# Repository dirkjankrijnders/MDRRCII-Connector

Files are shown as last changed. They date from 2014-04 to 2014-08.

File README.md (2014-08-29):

MDRRCII-Connector
=================

This is a small interface board to connect the [Mini STM32 board](http://www.ebay.com/itm/MINI-V3-STM32F103RBT6-development-board-with-2-8-TFT-module-/121287420704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) as used in [MDRRC II](http://members.home.nl/robert.evers/mdrrc2.htm) its peripherals. It is effectively all of the schematics in the manual on a nice board. It uses a DIN5 connector for I2C controller and also has a [S88N](http://www.s88-n.eu) pin-compatible RJ45 connection. Its power it receives from a 4-pin molex connector as commonly found in computers. By default this also powers the STM32, which is not desirable unless an USB isolator is used. 

It also includes a USB isolator, not necessary for normal operation, but when fiddling around I'd rather blow the 10 euro isolator than my laptops usb port. It also 

Unchecked Reichelt shopping card:
http://www.reichelt.de/?ACTION=20;AWKID=901501;PROVID=2084

STATUS
------
Board for Rev.0 are on order and recieved. The first board is build and very lightly tested with MDRRC version one, due to a rather lengthy remodeling of my train room (well actually, the creation of...). Below is a photo of the prototype. Testing with MDRRC-II is under way though.

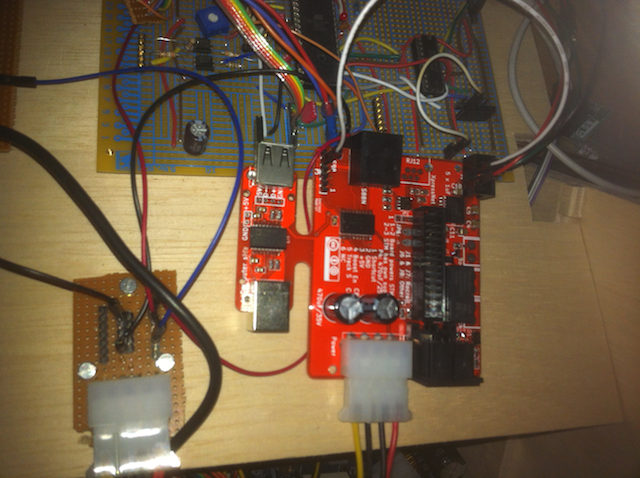
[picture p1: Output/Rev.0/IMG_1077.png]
Photo of the first prototype


<table>
<tr>
<th>Function</th><th>test</th>
</tr>
<tr><td>Power</td><td>Passed</td></tr>
<tr><td>Booster connection</td><td>Passed</td></tr>
<tr><td>S88N</td><td>Passed*</td></tr>
<tr><td>I2C</td><td>Failed, see issue #1</td></tr>
<tr><td>Programming</td><td>Untested</td></tr>
<tr><td>Expressnet</td><td>Untested</td></tr>
</table>
* Works, but S88N signal specifications remain untested until now.

LICENSE
-------

Both hardware and firmware are placed under the Creative Commons Attribution-ShareAlike 3.0 Unported License. See <http://creativecommons.org/licenses/by-sa/3.0/> and License.txt for more details.

Copyright 2014
Dirkjan Krijnders
<dirkjan@krijnders.net>

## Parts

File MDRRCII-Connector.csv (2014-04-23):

ref | value | Field1 | Field2 | Field3 | Field4 | Field5 | Field6 | Field7 | Field8
C1 | 100nF
C2 | 100nF
C3 | 100nF
C4 | 1uF
C5 | 1uF
C6 | 470uF/35V
C7 | 100nF
C8 | 470uF/25V
C9 | 100nF
C10 | 1uF
C11 | 1uF
C12 | 100nF
C13 | 1uF
C14 | 33nF
D1 | S1G
D2 | S1G
J1 | SOLDER_JUMPER_CONN
J2 | USB
J3 | RJ12
J4 | USB_2 | VCC | D+ | D- | GND
J5 | RJ45
J6 | SOLDER_JUMPER
J7 | SOLDER_JUMPER_CONN
J8 | SOLDER_JUMPER
JP1 | JUMPER
K1 | RELAY_M4
P1 | DIN_5
P2 | CONN_4
P3 | CONN_STM32_P1
P4 | CONN_3X2
P5 | CONN_6
P6 | CONN_2
P7 | CONN_4
P8 | CONN_2
P9 | CONN_2
P10 | CONN_2
Q1 | BC847
R1 | 1K
R2 | 1K
R3 | 1K
R4 | 100
R5 | 100
R6 | 24 1%
R7 | 4K7
R8 | 24 1%
R9 | 4K7
R10 | 120
R11 | 1K5
R12 | 1K5
R13 | 24 1%
R14 | 24 1%
R15 | 39
R16 | 680
R17 | 1K
R18 | 47k
U1 | MAX485
U2 | ADuM4160 | 2061081 | ADUM 4160
U3 | MAX232 | 9725962 | MAX 232 CWE
U4 | 74LS244
U5 | PC814

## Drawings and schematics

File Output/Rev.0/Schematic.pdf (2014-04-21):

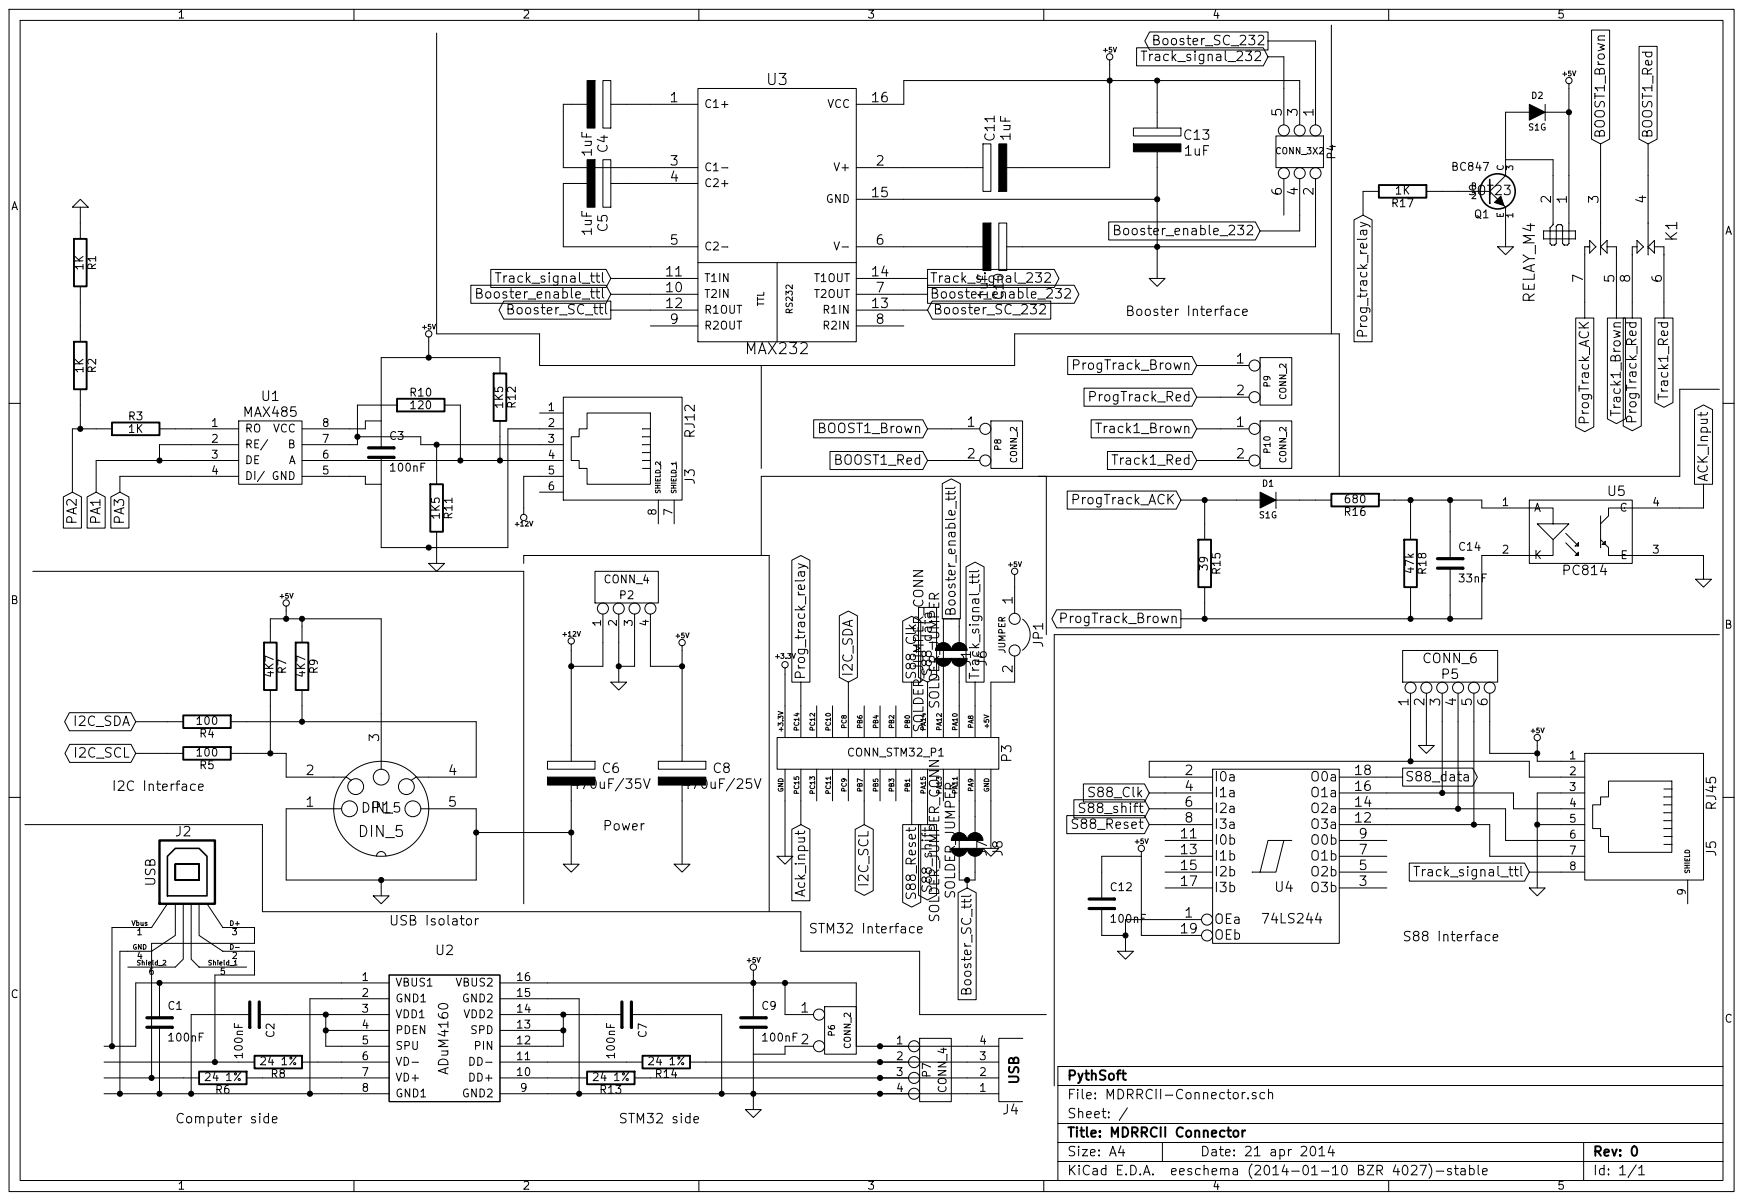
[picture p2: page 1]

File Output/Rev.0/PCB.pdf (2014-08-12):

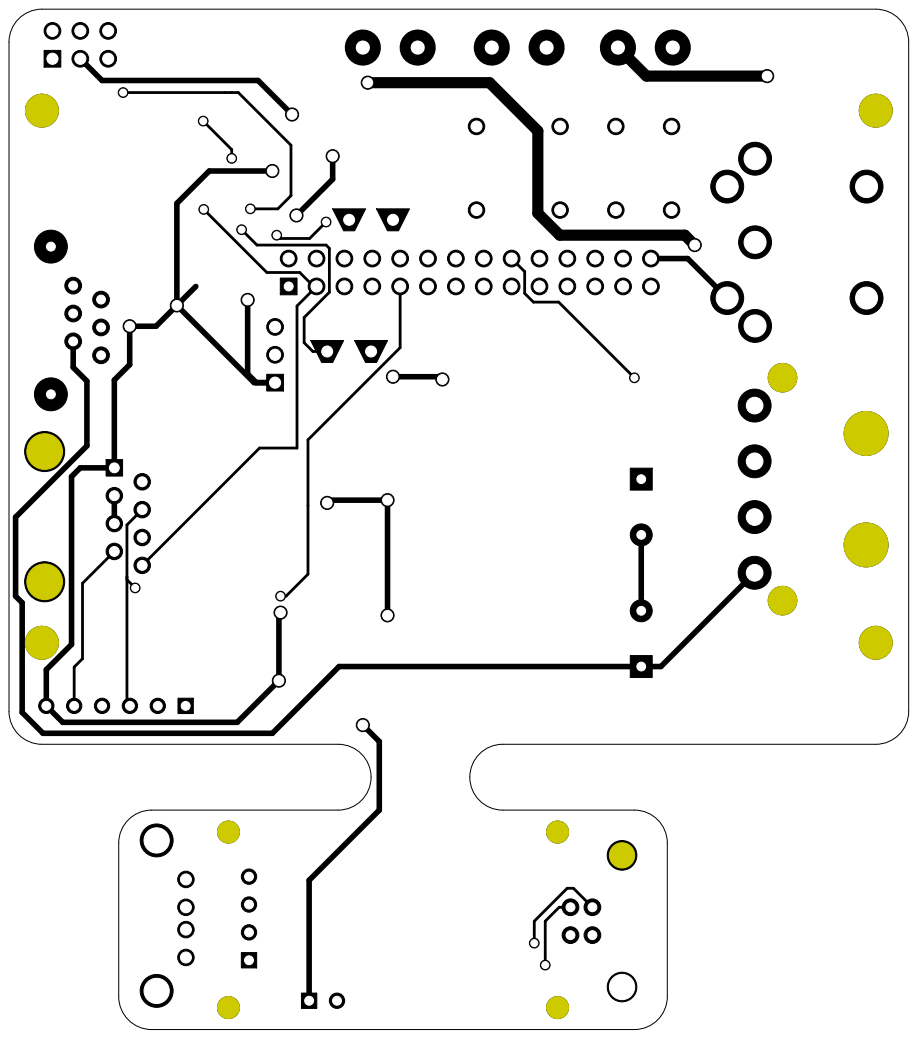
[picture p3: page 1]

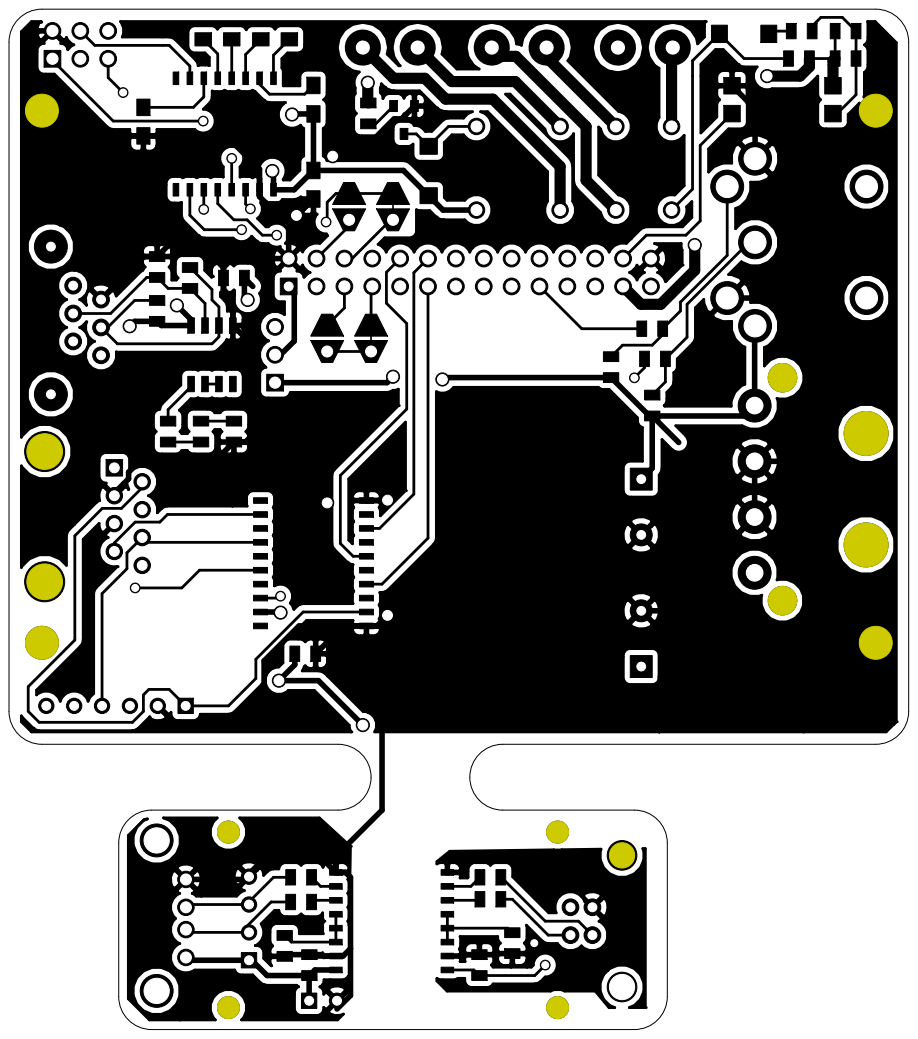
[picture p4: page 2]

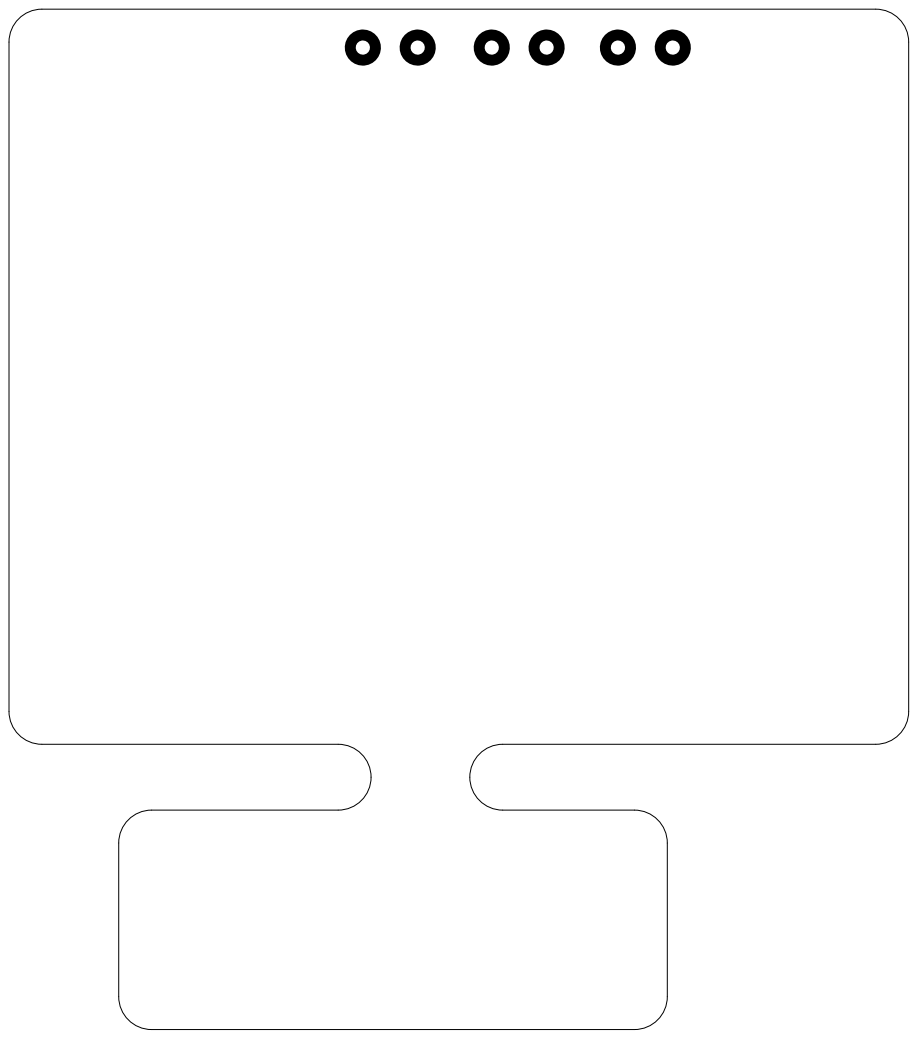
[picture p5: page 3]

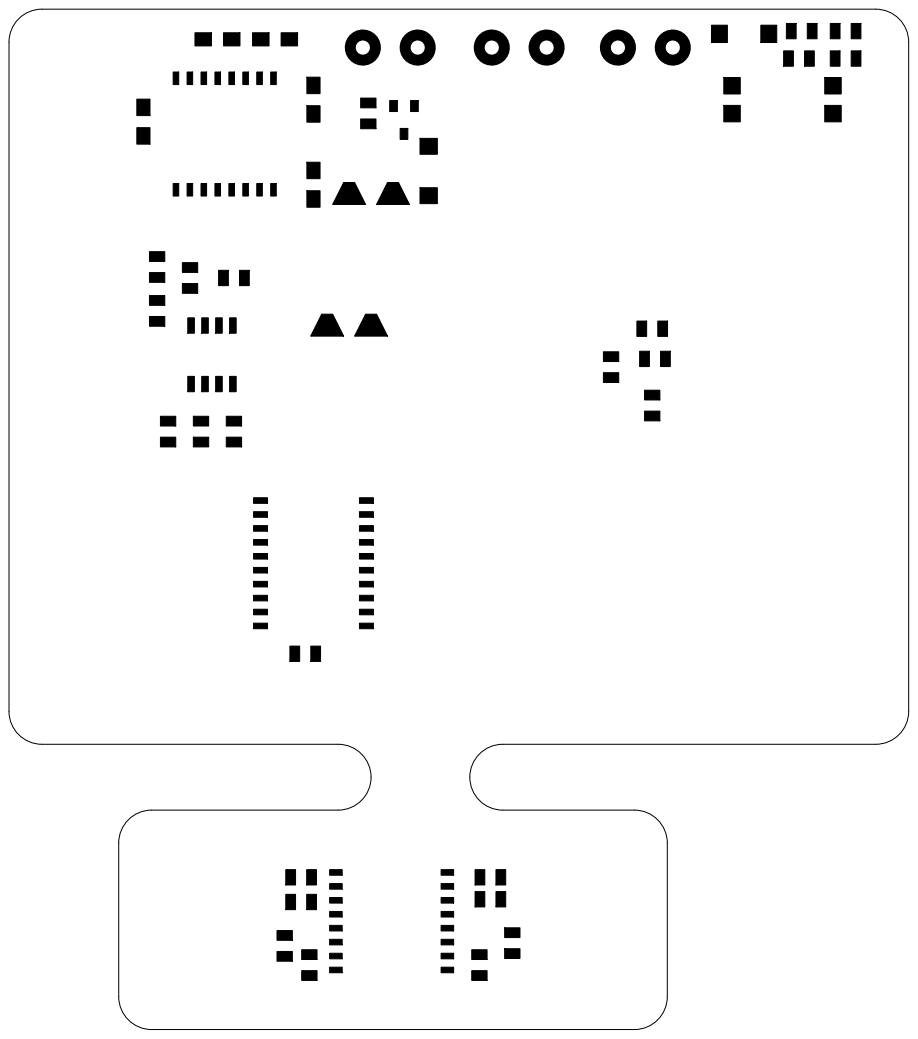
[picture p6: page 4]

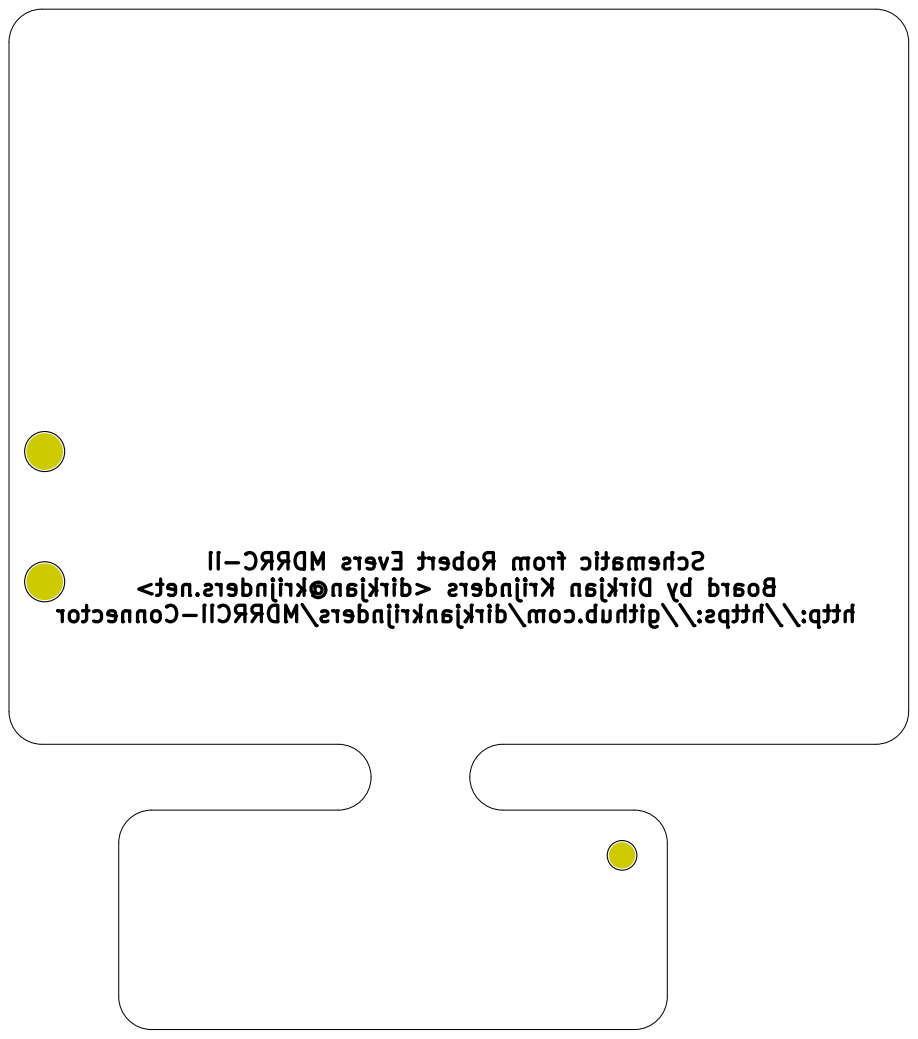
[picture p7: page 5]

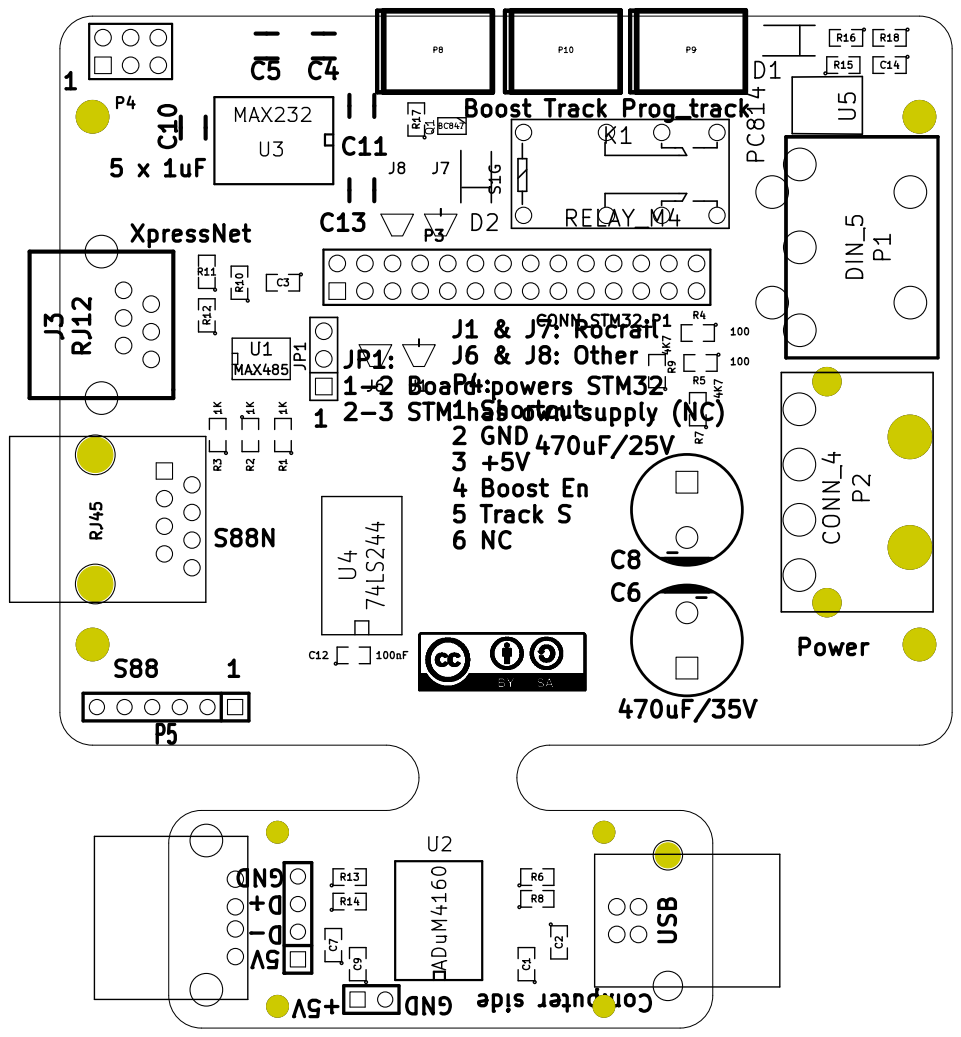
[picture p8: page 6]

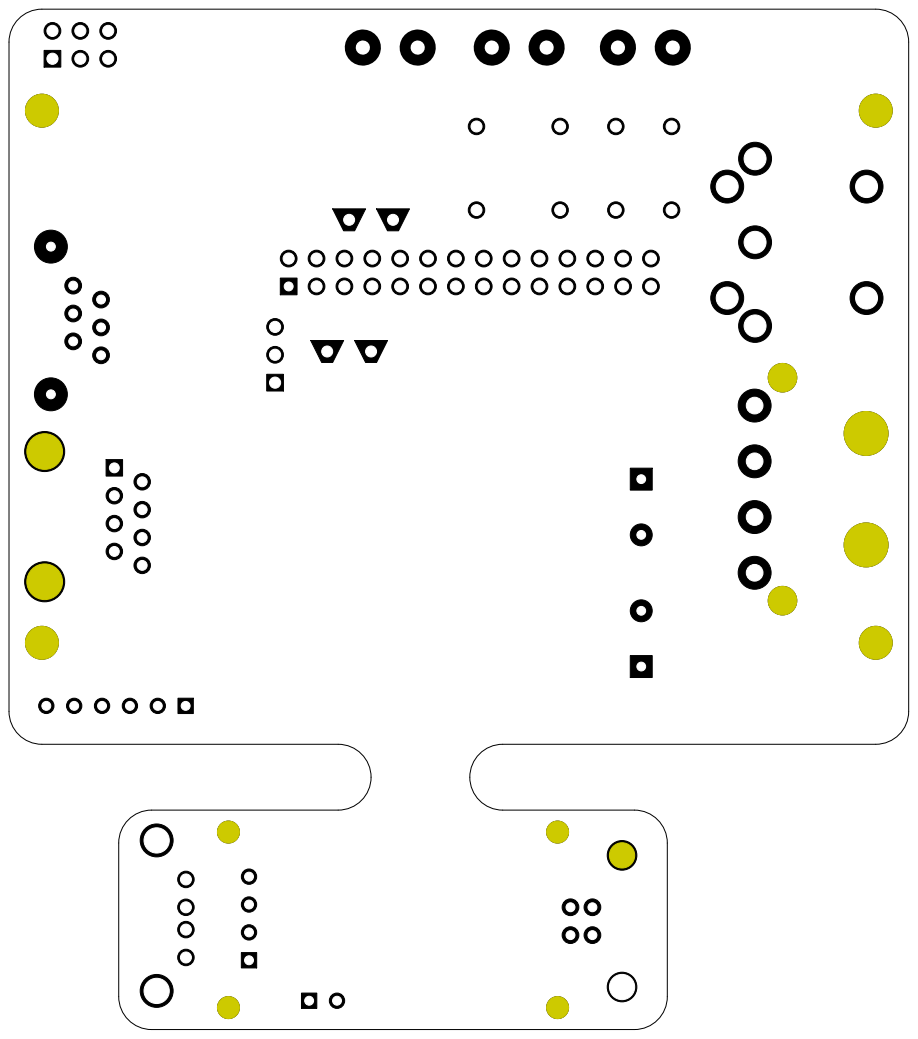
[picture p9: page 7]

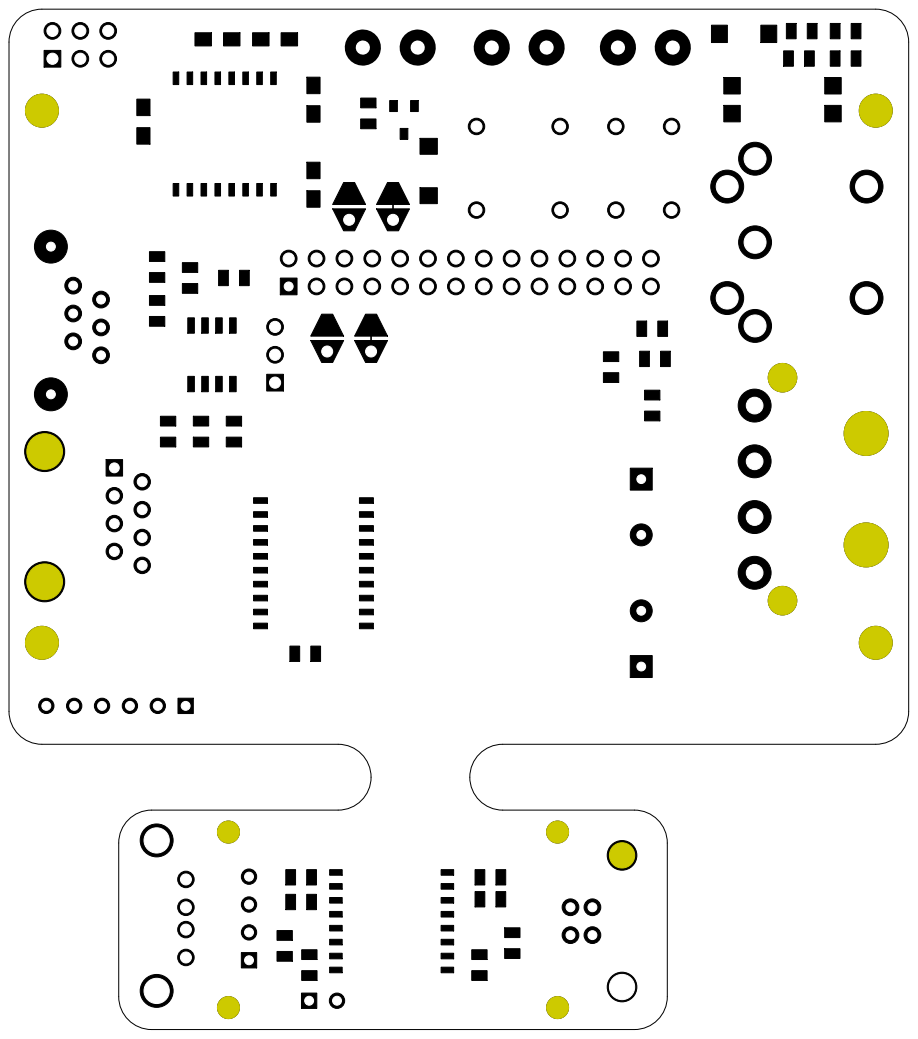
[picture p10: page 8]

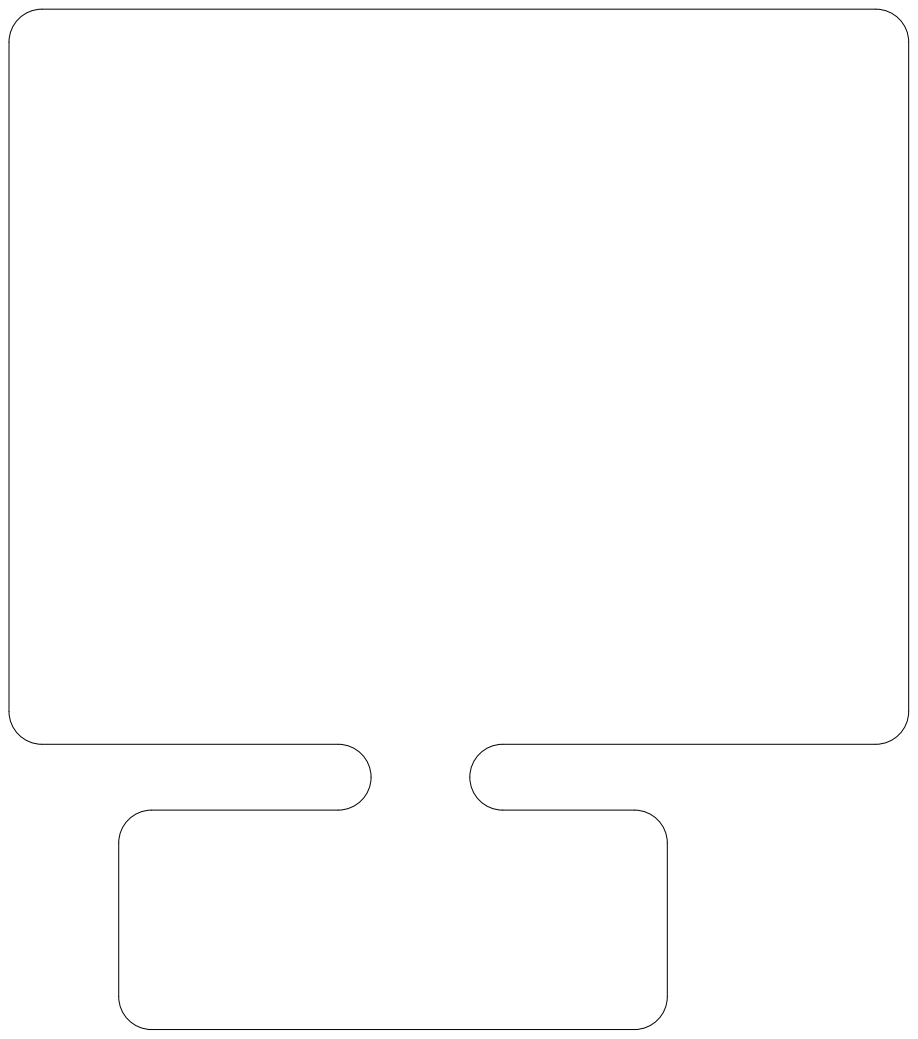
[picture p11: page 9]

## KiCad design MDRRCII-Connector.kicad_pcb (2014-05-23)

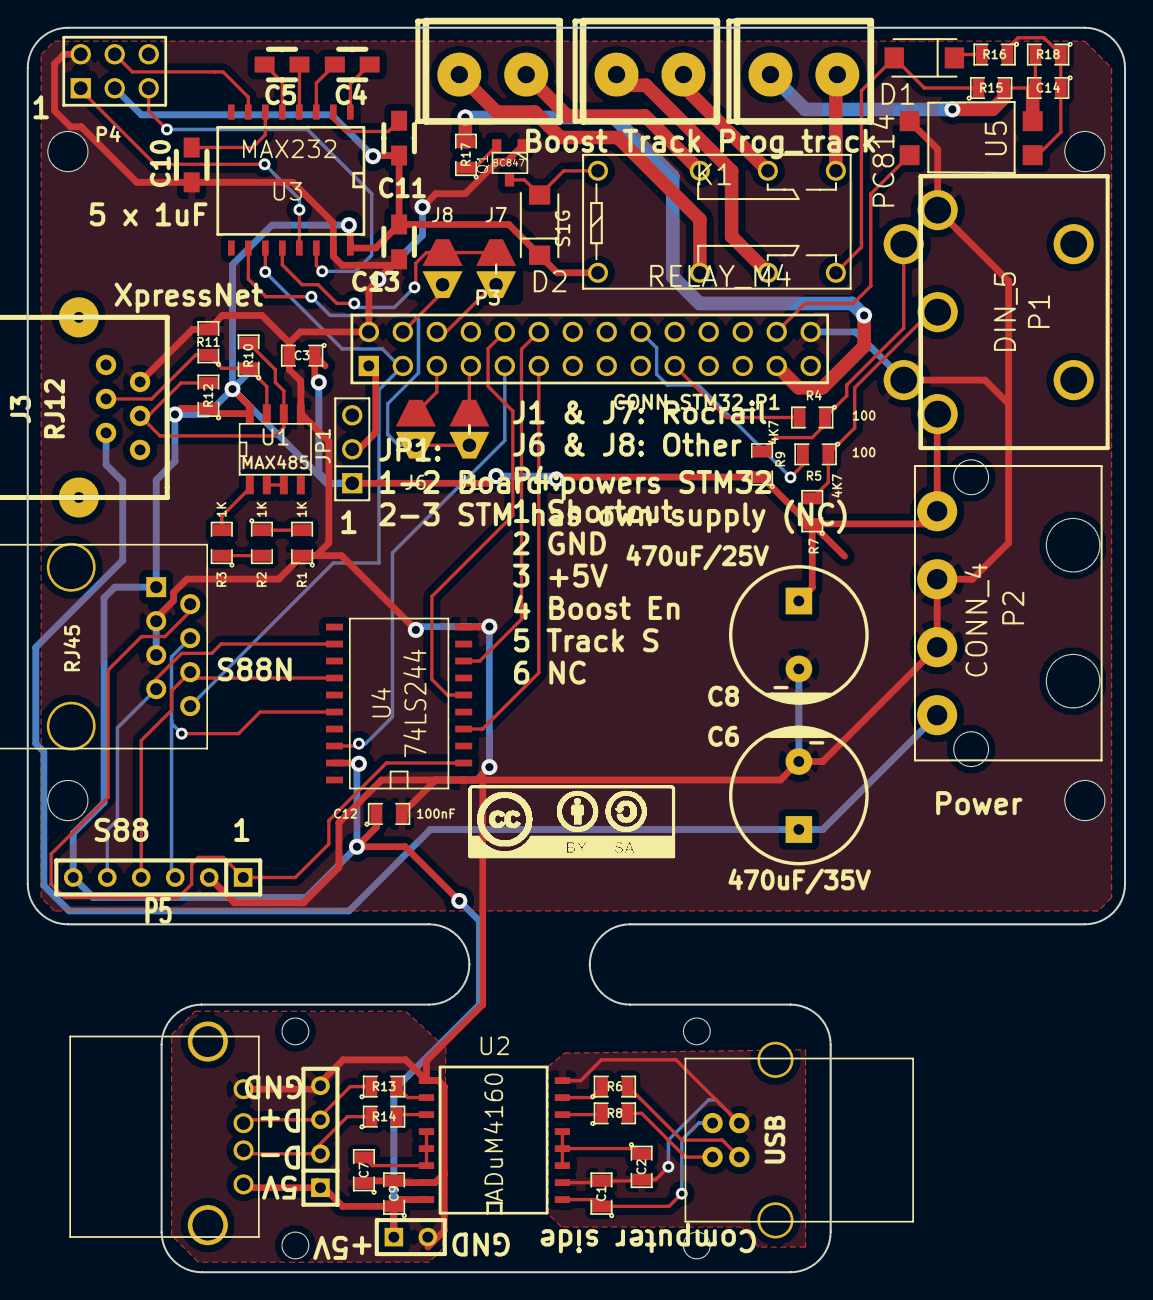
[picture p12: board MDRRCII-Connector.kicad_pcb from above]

Board: 2 copper layers, 82.0 x 93.0 mm, 68 parts (0 on the bottom side), 63 nets.

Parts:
C1, C2, C3, C7, C9, C12: 100nF; SM0805
C4, C5, C10, C11, C13: 1uF; Capacitor_SMD0805_HandSoldering_RevA_Date21Jun2010
C6: 470uF/35V; CP_10x21mm
C8: 470uF/25V; CP_10x21mm
C14: 33nF; SM0805
D1, D2: S1G; DO-214AC
J1, J7: SOLDER_JUMPER_CONN; solder_jumper_conn
J2: USB; USB_B
J3: RJ12; RJ12_E
J4: USB_2; USB_A
J5: RJ45; RJ45_8
J6, J8: SOLDER_JUMPER; solder_jumper
JP1: JUMPER; PIN_ARRAY_3X1
K1: RELAY_M4; Relais_M4
M2, M2#2, M2#3, M2#4, M2#5, M2#6, M2#7, M2#8: VAL**; M2
P1: DIN_5
P2: CONN_4; MOLEX_15-24-4441
P3: CONN_STM32_P1; pin_array_14x2
P4: CONN_3X2; pin_array_3x2
P5: CONN_6; SIL-6
P6: CONN_2; SIL-2
P7: CONN_4; SIL-4
P8, P9, P10: CONN_2; 2PIN_SC_RM5
Q1: BC847; SOT23
R1, R2, R3, R17: 1K; SM0805
R4, R5: 100; SM0805
R6, R8, R13, R14: 24 1%; SM0805
R7, R9: 4K7; SM0805
R10: 120; SM0805
R11, R12: 1K5; SM0805
R15: 39; SM0805
R16: 680; SM0805
R18: 47k; SM0805
U1: MAX485; SO8E
U2: ADuM4160; SO16W
U3: MAX232; SO16W
U4: 74LS244; SO20L
U5: PC814; 4LD_MDIP

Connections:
+5V: C3.1, C8.1, C9.1, C11.2, C12.1, C13.1, D2.2, J4.4, J5.1, JP1.1, K1.1, P1.3, P2.4, P4.3, P5.6, P6.1, P7.1, R7.1, R9.1, R12.1, U1.8, U2.16, U3.16, U4.19
+12V: C6.1, J3.5, P2.1
ACK_Input: P3.26, U5.4
BOOST1_Brown: K1.3, P8.1
BOOST1_Red: K1.4, P8.2
Booster_SC_232: P4.1, U3.13
Booster_SC_ttl: J7.1, J8.1, U3.12
Booster_enable_232: P4.4, U3.7
Booster_enable_ttl: J1.2, J6.2, U3.10
GND: C3.2, C6.2, C7.1, C8.2, C9.2, C10.1, C12.2, C13.2, J3.2, J4.1, J5.3, J5.5, P1.1, P1.5, P2.2, P2.3, P3.2, P3.28, P4.2, P5.2, P6.2, P7.4, Q1.1, R1.1, R11.2, U1.5, U2.9, U2.15, U3.15, U4.1, U4.10, U5.3
I2C_SCL: P3.18, R5.2
I2C_SDA: P3.19, R4.2
unnamed: D2.1, K1.2, Q1.3
unnamed: Q1.2, R17.1
unnamed: J3.3, R10.1, R11.1, U1.7
unnamed: J3.4, R10.2, R12.2, U1.6
unnamed: R3.2, U1.1
unnamed: R1.2, R2.1
unnamed: P1.2, R5.1, R7.2
unnamed: P1.4, R4.1, R9.2
unnamed: D1.2, R16.2
unnamed: C14.1, R16.1, R18.1, U5.1
unnamed: J8.2, P3.4
unnamed: J1.1, P3.7
unnamed: J6.1, P3.5
unnamed: JP1.2, P3.1
unnamed: J7.2, P3.6
unnamed: C4.2, U3.3
unnamed: C5.2, U3.5
unnamed: J4.3, P7.2, R14.1
unnamed: J4.2, P7.3, R13.1
unnamed: J5.2, P5.1, U4.2
unnamed: J5.4, P5.3, U4.16
unnamed: J5.7, P5.5, U4.12
unnamed: C10.2, U3.6
unnamed: C4.1, U3.1
unnamed: C5.1, U3.4
unnamed: C11.1, U3.2
unnamed: C1.1, J2.1, U2.1
unnamed: R14.2, U2.11
unnamed: R13.2, U2.10
unnamed: C7.2, U2.12, U2.13, U2.14
unnamed: C2.1, U2.3, U2.4, U2.5
unnamed: J5.6, P5.4, U4.14
unnamed: C1.2, C2.2, J2.4, U2.2, U2.8
unnamed: R8.1, U2.6
unnamed: J2.2, R8.2
unnamed: R6.1, U2.7
unnamed: J2.3, R6.2
PA1: U1.2, U1.3
PA2: R2.2, R3.1
ProgTrack_ACK: D1.1, K1.7, R15.1
ProgTrack_Brown: C14.2, P9.1, R15.2, R18.2, U5.2
ProgTrack_Red: K1.8, P9.2
Prog_track_relay: P3.25, R17.2
S88_Clk: P3.11, U4.4
S88_Reset: P3.12, U4.8
S88_data: P3.9, U4.18
S88_shift: P3.10, U4.6
Track1_Brown: K1.5, P10.1
Track1_Red: K1.6, P10.2
Track_signal_232: P4.5, U3.14
Track_signal_ttl: J5.8, P3.3, U3.11

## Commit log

2014-04-21 Rev 0 roughly done
    [MDRRCII-Connector.kicad_pcb, MDRRCII-Connector.sch]
2014-04-21 Small cleanup on schematic and PDF creation
    [MDRRCII-Connector.sch]
2014-04-23 Added some SKUs and BOM
    [MDRRCII-Connector.csv, MDRRCII-Connector.sch]
2014-05-23 Kicad version update
    [MDRRCII-Connector.kicad_pcb]
2014-05-23 Silkscreen and mounting holes updated
    [MDRRCII-Connector.kicad_pcb]
2014-05-23 Fixed silkscreen around R4, R5, R7 and R9
    [MDRRCII-Connector.kicad_pcb]
2014-08-12 Added PDF with the board
2014-08-13 Added picture of build PCB in action
